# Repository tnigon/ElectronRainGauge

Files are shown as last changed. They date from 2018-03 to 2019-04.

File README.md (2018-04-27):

# Electron Weather Station


## Summary
This repository contains the files that I used to create a "cloud-connected" weather station via the [Particle Electron](https://store.particle.io/collections/electron). Please see [my how-to guide](http://tylernigon.me/projects/weather_station.html) describing the steps I took.

## Files
- The [circuit_board](https://github.com/tnigon/Electron_weather-station/tree/master/circuit_board) folder contains items for designing and manufacturing the printed circuit board (pcb).
- The [particle_code](https://github.com/tnigon/Electron_weather-station/tree/master/particle_code) folder contains the .ino files that contain the user-readable Particle code. These can be loaded or copied and pasted into Particle's [IDE](https://build.particle.io/build) to modify the code and/or compile to binary.
- [binary](https://github.com/tnigon/Electron_weather-station/tree/master/binary) contains a blank binary file that can be flashed to the Electron to stop publishing. This came in handy for me when troubleshooting my code and I didn't quite have it right.
- [webhook_templates](https://github.com/tnigon/Electron_weather-station/tree/master/webhook_templates) contains webhook templates for publishing your data to ThingSpeak or Weather Underground. Note that device ID and webhook name should be modified to be used with your device.

## Author
- [Tyler Nigon](https://tylernigon.me)

## License
This project is licensed under the GNU General Public License - see the [LICENSE.md](https://github.com/tnigon/Electron_weather-station/blob/master/LICENSE) for details

## Change log
- v2.0:
- v2.1:
- v2.2:

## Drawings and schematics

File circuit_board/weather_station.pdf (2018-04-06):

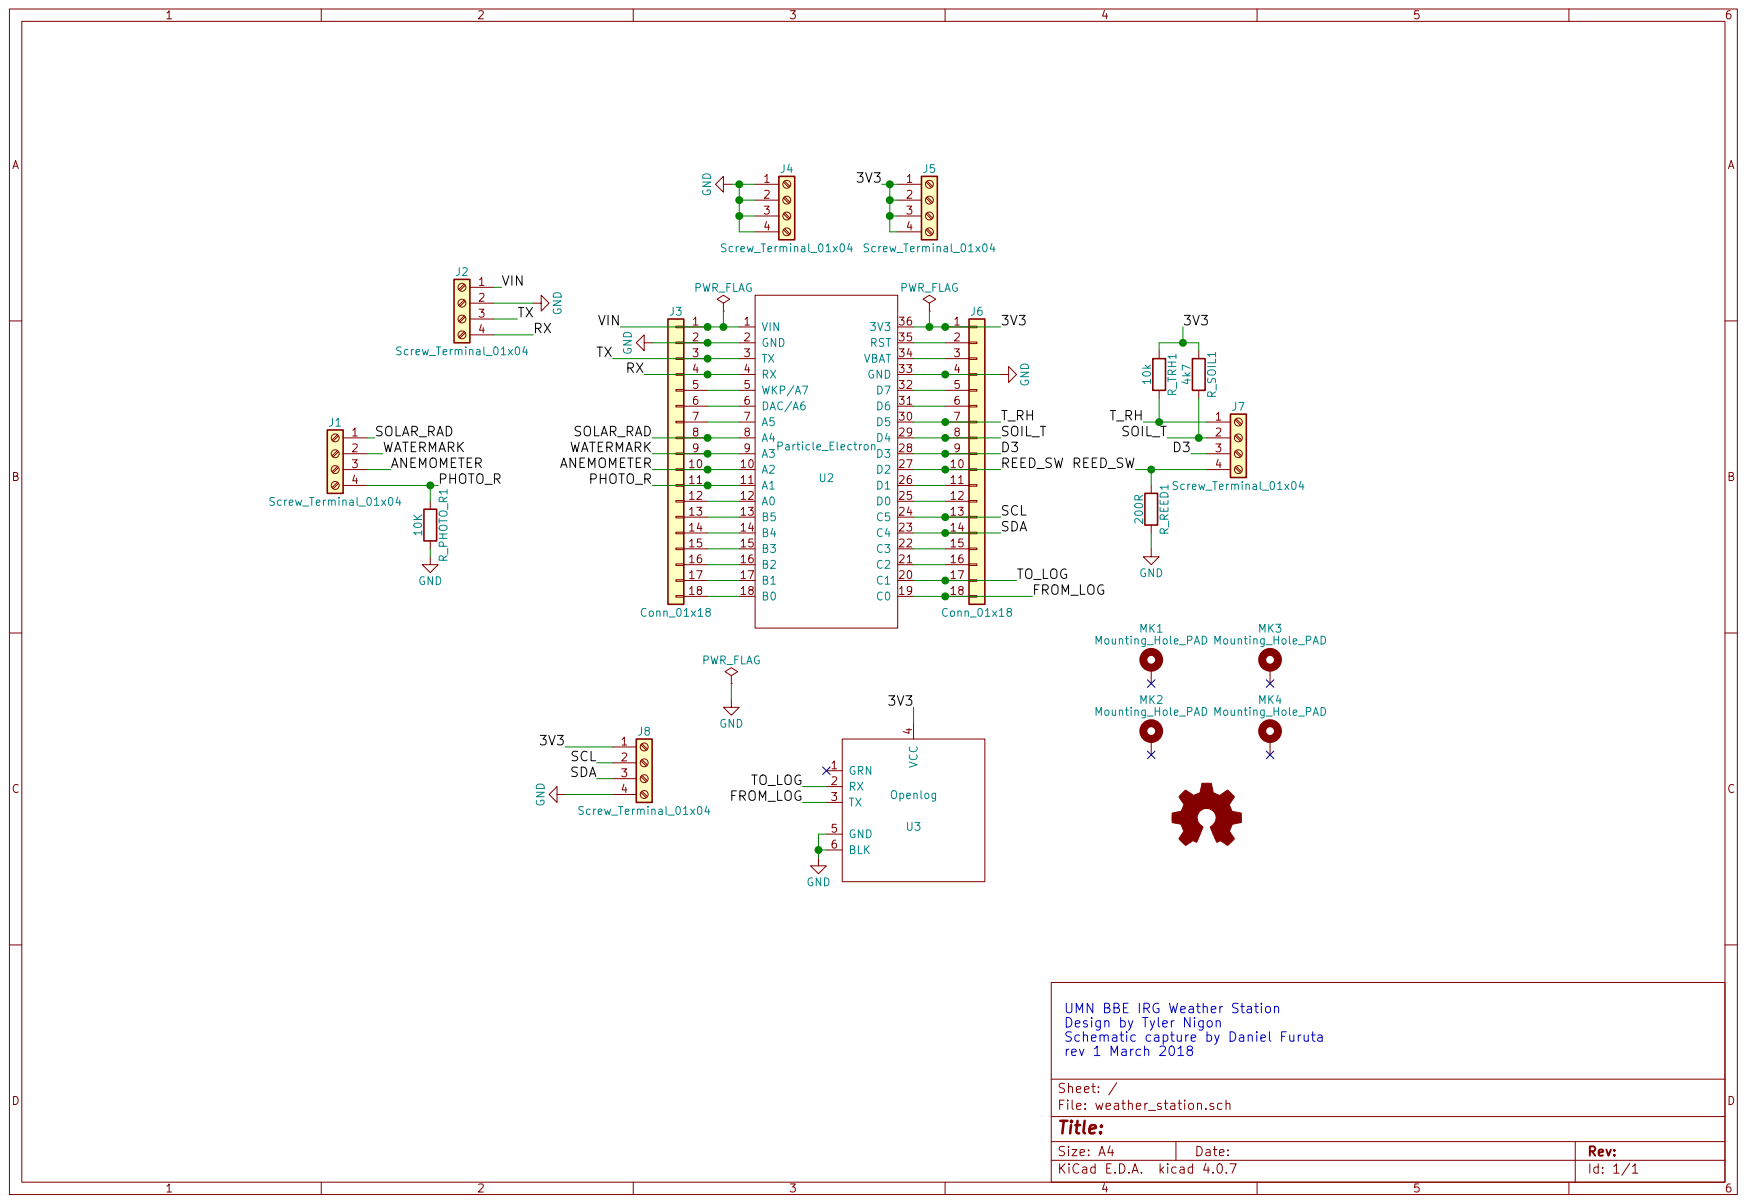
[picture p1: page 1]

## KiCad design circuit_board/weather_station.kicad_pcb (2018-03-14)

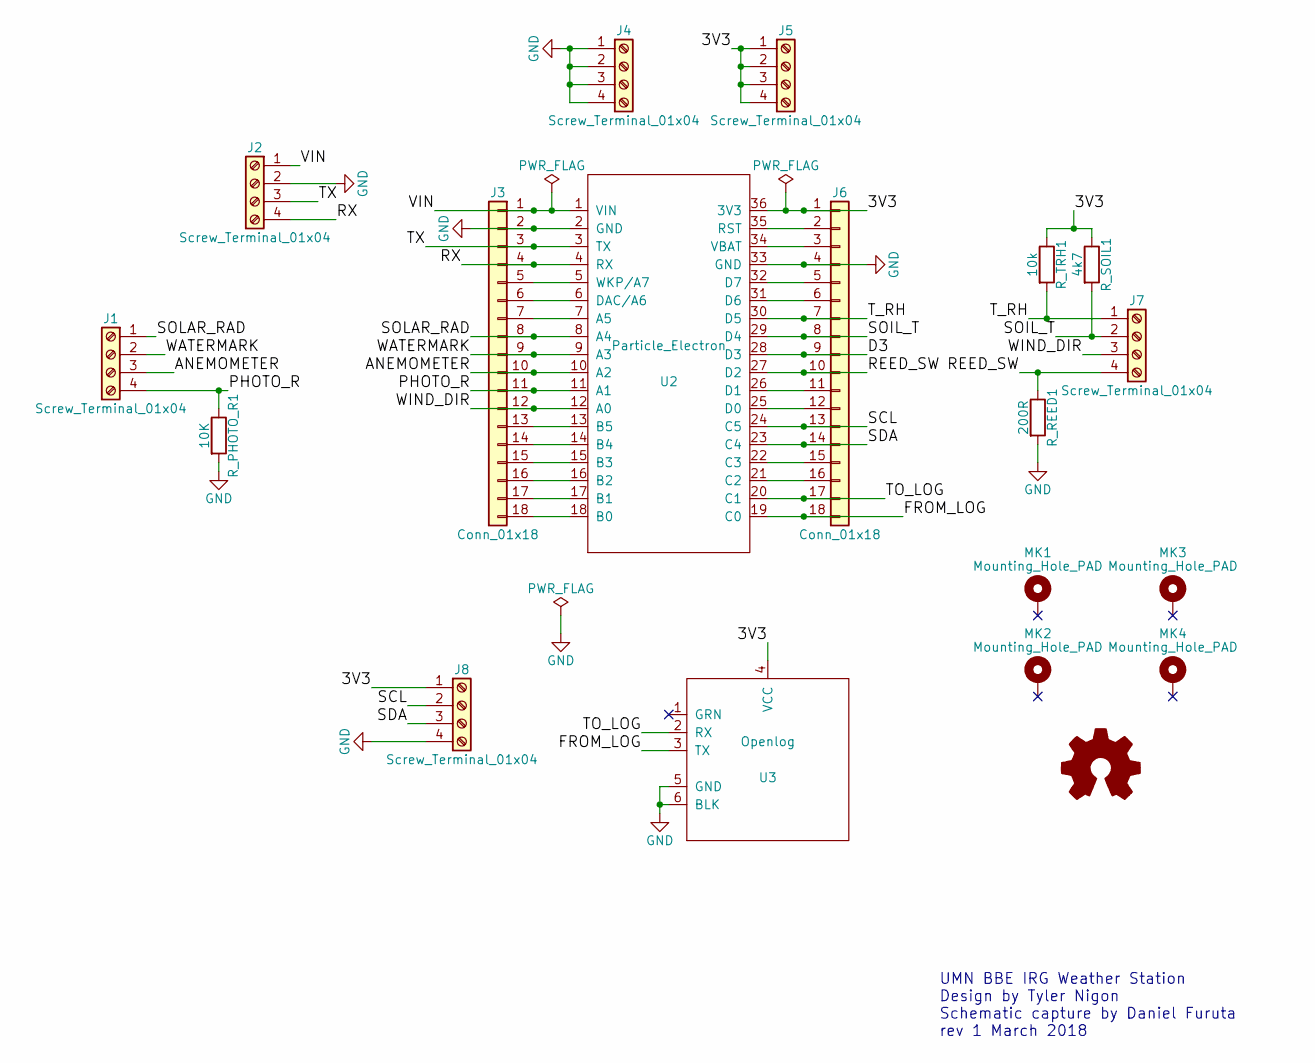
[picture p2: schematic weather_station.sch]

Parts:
J1, J2, J4, J5, J7, J8: Screw_Terminal_01x04; TerminalBlock_04x3.5mm_Straight
J3, J6: Conn_01x18; Pin_Header_Straight_1x18_Pitch2.54mm
MK1, MK2, MK3, MK4: Mounting_Hole_PAD; MountingHole_3mm_Pad
R_PHOTO_R1: 10K; R_TH_0.25W_400mil
R_REED1: 200R; R_TH_0.25W_400mil
R_SOIL1: 4k7; R_TH_0.25W_400mil
R_TRH1: 10k; R_TH_0.25W_400mil
U2: Particle_Electron
U3: Openlog

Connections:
/3V3: J5.1, J5.2, J5.3, J5.4, J6.1, J8.1, R_SOIL1.1, R_TRH1.1, U2.36 (3V3), U3.4 (VCC)
/ANEMOMETER: J1.3, J3.10, U2.10 (A2)
/D3: J6.9, U2.28 (D3)
/FROM_LOG: J6.18, U2.19 (C0), U3.3 (TX)
/PHOTO_R: J1.4, J3.11, R_PHOTO_R1.1, U2.11 (A1)
/REED_SW: J6.10, J7.4, R_REED1.1, U2.27 (D2)
/RX: J2.4, J3.4, U2.4 (RX)
/SCL: J6.13, J8.2, U2.24 (C5)
/SDA: J6.14, J8.3, U2.23 (C4)
/SOIL_T: J6.8, J7.2, R_SOIL1.2, U2.29 (D4)
/SOLAR_RAD: J1.1, J3.8, U2.8 (A4)
/TO_LOG: J6.17, U2.20 (C1), U3.2 (RX)
/TX: J2.3, J3.3, U2.3 (TX)
/T_RH: J6.7, J7.1, R_TRH1.2, U2.30 (D5)
/VIN: J2.1, J3.1, U2.1 (VIN)
/WATERMARK: J1.2, J3.9, U2.9 (A3)
/WIND_DIR: J3.12, J7.3, U2.12 (A0)
GND: J2.2, J3.2, J4.1, J4.2, J4.3, J4.4, J6.4, J8.4, R_PHOTO_R1.2, R_REED1.2, U2.2 (GND), U2.33 (GND), U3.5 (GND), U3.6 (BLK)
unnamed: J3.5, U2.5 (WKP/A7)
unnamed: J3.6, U2.6 (DAC/A6)
unnamed: J3.7, U2.7 (A5)
unnamed: J3.13, U2.13 (B5)
unnamed: J3.14, U2.14 (B4)
unnamed: J3.15, U2.15 (B3)
unnamed: J3.16, U2.16 (B2)
unnamed: J3.17, U2.17 (B1)
unnamed: J3.18, U2.18 (B0)
unnamed: J6.2, U2.35 (RST)
unnamed: J6.3, U2.34 (VBAT)
unnamed: J6.5, U2.32 (D7)
unnamed: J6.6, U2.31 (D6)
unnamed: J6.11, U2.26 (D1)
unnamed: J6.12, U2.25 (D0)
unnamed: J6.15, U2.22 (C3)
unnamed: J6.16, U2.21 (C2)

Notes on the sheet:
UMN BBE IRG Weather Station Design by Tyler Nigon Schematic capture by Daniel Furuta rev 1 March 2018

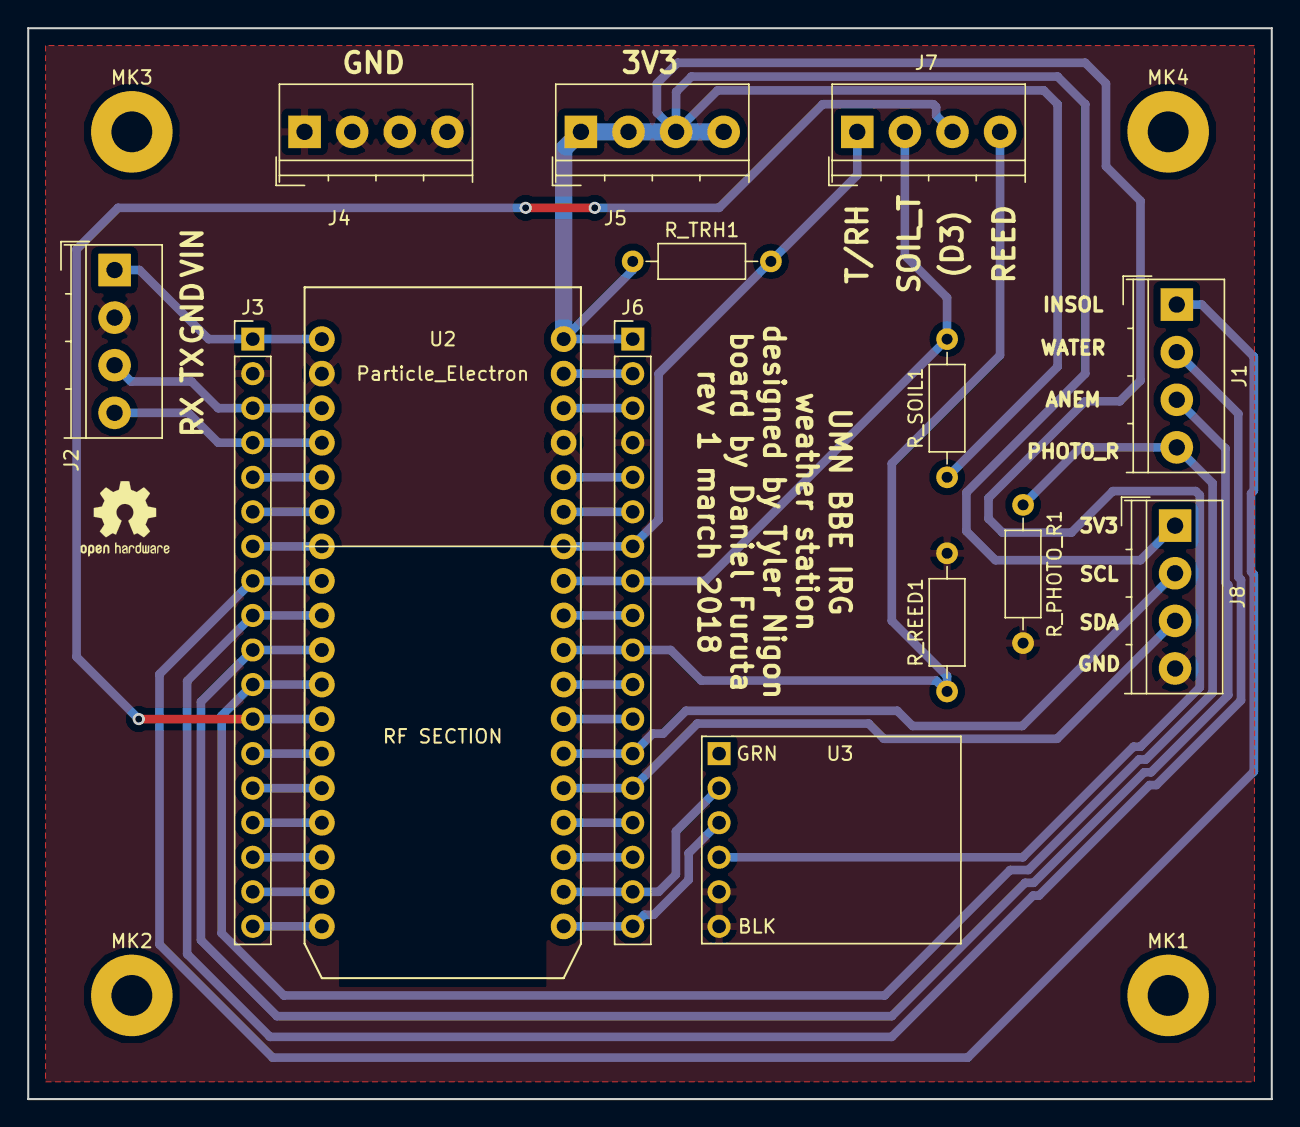
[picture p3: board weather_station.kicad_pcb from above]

Board: 2 copper layers, 91.4 x 78.7 mm, 18 parts (0 on the bottom side), 35 nets.

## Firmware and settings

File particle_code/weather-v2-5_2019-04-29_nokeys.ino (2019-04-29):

// This #include statement was automatically added by the Particle IDE.

#include <DHT.h> // Temp/humidity sensor
#include <Wire.h> // Lux sensor
#include <Adafruit_Sensor.h> // Lux sensor
#include <Adafruit_TSL2591.h> // Lux sensor
#include <DS18B20.h> // Waterproof temperature sensor
#include "Serial5/Serial5.h"

// Updated: 10 April 2019
// Author: Tyler J. Nigon

// For:
// Device name: <Particle device name>
// Device ID: <Particle device ID>
// Device firmware: <Electron device firmware>
// Code version: 2.5.0
// Owner: <Particle device owner>

// ============================================================
// Global user parameters
// ============================================================
// ***** Code version ******
String code_ver = "2.5.0";  // required for Weather Cloud

// ****** Time ******
boolean daylight_savings = true; // DST begins in spring and ends in fall
int gmt_timeZone = -6; // Change to appropriate time zone for your device
unsigned int sensorCapturePeriod = (30); // units are seconds
unsigned int publishPeriod = (60*10);  // units are seconds

// ****** Sensors ******
boolean sense_dht = true; // temp/humidity sensor
boolean sense_photo = false; // photoresistor light sensor
boolean sense_tsl = false; // tsl lux sensor
boolean sense_rain = true; // tipping bucket rain gauge
boolean sense_wind = true; // anemometer sensor
boolean sense_dir = false; // wind direction sensor
boolean sense_moist = false; // soil moisture sensor
boolean sense_soiltemp = true; // soil temperature sensor
boolean sense_solrad = false; // LI-200R pyranometer

// ****** Testing ******
boolean testing = false; // Uses benchTime instead of initialTime

// ****** Publishing ******
// ** If publishing via webhook, be sure channel, key/pw, name and number of variables are correct **
boolean units_imperial = false; // Temp, wind, and rain reported in imperial units (F, mph, & inches)

boolean publish_particle = false;
boolean publish_thingspeak = false;  // Go to #1
boolean publish_wunderground = false;  // Go to #2
boolean publish_weathercloud = true;  // Got to #3
boolean publish_serial = false;  // Go to #4
boolean publish_sd = false;

// [1: Thinkgspeak]
unsigned long thingspeakChannelNumber = 012345;
String api_key = ""; // ThingSpeak Write API Key.
String webhook_ts_str = ""; // Name of webhook - must match from "Integrations" page
// [2: Weather Underground]
String wu_stationID = ""; // From WUnderground account
String wu_password = "";
String webhook_wu_str = "";
// String webhook_wu_str_rain = "webhook_wunderground_rain";
// String webhook_wu_str_norain = "webhook_wunderground_norain";
// [3: Weather Cloud]
String weathercloud_id = "";  // From Weather Cloud account
String weathercloud_key = "";
String weathercloud_type = "d407ac9be248";  // Device code from WeatherCloud
String webhook_wc_str = "";
// [4: Serial/SD]
SYSTEM_MODE(SEMI_AUTOMATIC); // Allows device to output to serial without being connected to the cloud

// ****** Sensors & pins ******
#define DHTPIN 5
#define DHTTYPE DHT22  // DHT11 (blue) or DHT22 (white)
DHT dht(DHTPIN, DHTTYPE);
int light_sensor_pin = A1;
// const int sleep_pin = D1;
const int RainPin = D2;
const int anemometerPin = A2;
const int wind_dir_pin = A0;
DS18B20 ds18b20(D4, true); // Waterproof temperature sensor
const int led = D7;
const int soil_moist_pin = A3;
int ledState = LOW; // ledState used to set the LED
// Adafruit_ADS1115 ads1115;
Adafruit_TSL2591 tsl = Adafruit_TSL2591(2591); // lux - 2591 identifies the sensor (multiple possible)
int solrad_sensor_pin = A4;
// ParticleSoftSerial SoftSer(C0, C1);

// ****** Other global variables ******
boolean cloud_connect;
float offsetDST = Time.getDSTOffset(); // Get current DST offset; default is +1.0
unsigned int sensorCount = 1; // this provides 32 bits of dynamic range
unsigned int publishCount = 1;
time_t benchTime;
time_t initialTime;
time_t endOfDay;
time_t scheduledSensor;
time_t scheduledPublish;
time_t time_wake;
time_t wake_secs;
String end_day;
boolean first_loop = true;
String header;

float dilToday = 0; // Daily Integrated Light (mol / m2 / day); resets at midnight
float lux2par = (1/54);
float dil_conversion = lux2par * (1/1000000) * (sensorCapturePeriod); // lux to par and micromoles to moles and seconds to "sensorCapturePeriod" (e.g., 5 seconds)
float solrad_offset = 2; // determine offset by disconnecting sensor from voltage amplifier and monitor voltage output
float solrad_gain = 0.05;  // units of V per microamp
float solrad_const = 62.28; // units of microamps per 1000 watts per m2 (this calibration constant comes from the Li-Cor certificate of calibration)
float solrad_conversion = 1/(solrad_gain * solrad_const); // in units of kW m-2 V-1 --> use this to directly convert voltage output to W m-2
// ============================================================

// Sensors
float tempC;
float humidityRH;
float dewPointC;
double Td_a = 17.271;  // Constants for dew point calculation
double Td_b = 237.7;  // See http://en.wikipedia.org/wiki/Dew_point
float heatIndexC;
float temp_f;
float dewPoint_f;
float heatIndex_f;
float light;
float lux;
float lux_tot;
float lux_n;
float par;
float dil_increment;
float soil_temp_C;
float soil_temp_F;
float wind_mps;
float wind_gust;
float wind_mph;
float windGust_mph;
float wind_dir;
float rainRateMultiplier;  // this variable extrapolates so hourly rate can be reported based on the chosen publishPeriod
float rain_mm;
float hourly_rain_mm;
float rainToday_mm;
float rain_in;
float hourly_rain_in;
float rainToday_in;
float soilMoisture;
float sol_rad_wm2;
float sol_rad_MJ;
float solrad_today_MJ;
// pin_t wakeUpPins[2] = {sleep_pin, RainPin};  // Initialize sleep settings
// InterruptMode edgeTriggerModes[2] = {RISING, RISING};  // wakes Electron if either wake-up pin is RISING

String pub_dewPointC;
String pub_hum;
String pub_heatIndexC;
String pub_hourly_rain_mm;
String pub_rainToday_mm;
String pub_soilMoisture;
String pub_soil_temp_C;
String pub_sol_rad_wm2;
String pub_tempC;
String pub_wind_gust_mps;
String pub_wind_mps;

int wc_dewPointC;
int wc_hum;
int wc_heatIndexC;
int wc_hourly_rain_mm;
int wc_rainToday_mm;
int wc_soilMoisture;
int wc_soil_temp_C;
int wc_sol_rad_wm2;
int wc_tempC;
int wc_wind_gust_mps;
int wc_wind_mps;

// ============================================================
// Functions
// ============================================================
void setup();
void loop();
String hhmmss();
String yyyymmdd();
void test_sensors();
// void put_to_sleep();
void sd_serial_setup();
void blinkLight();
void captureTempHumidity();
float getAndResetTempC();
float getAndResetHumidityRH();
float getAndResetDewPointC();
float getAndResetHeatIndex();
void captureLight();
float getAndResetLight();
void captureLux();
float getAndResetLux();
float getAndResetLux1();
float getAndResetParDIL();
void captureSoilMoisture();
float getAndResetSoilMoisture();
void capture_soil_temp();
float getAndResetSoilTempC();
void initializeRainGauge();
void handleRainEvent();
float getAndResetRain();
void captureWind();
float getAndResetAnemometer();
void initializeWindVane();
void captureWindVane();
float getAndResetWindVaneDegrees();
float lookupRadiansFromRaw();
void capture_sol_rad_MJ();
float getAndResetSolrad();
void publishToSerial();
void publishToParticle();
void create_pub_json();
void publishToThingSpeak();
void publishToWeatherCloud();
void publishToWUndergroundRain();
void publishToWUndergroundAll();
void publishToWUndergroundNoRain();
void createThingSpeakjson();
void create_WC_json();
void createWUjsonAll();
void createWUndergroundjsonRain();
void createWUndergroundjsonNoRain();
double mapDouble();
// ============================================================

void setup() {
    // if (publish_serial == true) {
    Serial.begin(9600); // Required if publishing to Serial
    // }
    if ((publish_particle == true) || (publish_thingspeak == true) || (publish_weathercloud == true) || (publish_wunderground == true)) {
        cloud_connect = true;
        Particle.connect();
        delay(3000); // delay to let Particle get connected so time is correct
        while (Particle.connected() == false) {
            delay(1000); // delay to let Particle get connected so time is correct
        }
        Particle.publish("cloud_connect = true");
    }
    else {
        cloud_connect = false;
    }
    // ============================================================
    // Time
    // ============================================================
    pinMode(led, OUTPUT);
    benchTime = Time.now();
    while (Time.year(benchTime) < 2018) {
    // while (Time.year(benchTime < 2018)) {
        Particle.publish("benchTime is not correct: ", yyyymmdd(benchTime));
        Particle.publish("benchTime is not correct: ", hhmmss(benchTime));
        benchTime = Time.now();
        delay(5000);
    }
    if (cloud_connect == true) {
        Particle.publish("Initial system time is: ", hhmmss(benchTime));
      }
    // while (benchTime < 3600) {
    //     benchTime = Time.now(); // So all times are consistently calculated (it could presumably take several seconds to get through all code in which case times will be misaligned)
    // }
    if (Time.minute(benchTime) >= 30) {
        initialTime = benchTime + ((59 - Time.minute(benchTime))*60) + (60 - Time.second(benchTime)); // ensures initial time will be at top of the hour
        if (Time.hour(initialTime) < abs(gmt_timeZone)) {
            endOfDay = initialTime - ((Time.hour(initialTime))*60*60) - (gmt_timeZone*60*60);
        }
        else {
            endOfDay = initialTime + ((24 - Time.hour(initialTime))*60*60) - (gmt_timeZone*60*60);
        }
    }
    if (Time.minute(benchTime) < 30) {
        initialTime = benchTime + ((29 - Time.minute(benchTime))*60) + (60 - Time.second(benchTime)); // ensures initial time will be at bottom of the hour
        if (Time.hour(initialTime) < abs(gmt_timeZone)) {
            endOfDay = initialTime - ((Time.hour(initialTime))*60*60) - (gmt_timeZone*60*60) - (30*60); // benchTime.day is already tomorrow
        }
        else {
            endOfDay = initialTime + ((24 - Time.hour(initialTime))*60*60) - (gmt_timeZone*60*60) - (30*60); // benchTime.day is still today
        }
    }
    if (daylight_savings == true) {
        endOfDay -= int(offsetDST*60*60);  // Adding int makes the math correct; otherwise there's an extra 48 seconds..
    }

    // ============================================================
    // First publish will be at first top or bottom of the hour
    // (unless in testing mode)
    // ============================================================
    scheduledSensor = benchTime + sensorCapturePeriod; // schedule initial sensor reading immediately
    time_wake = scheduledPublish;  //  initialize so can go to sleep after first publish
    if (testing == true) {
        scheduledPublish = benchTime + publishPeriod;
    }
    else {
        scheduledPublish = initialTime; // schedule first publish at first top (or bottom) of the hour
    }
    end_day = yyyymmdd(endOfDay) + "T" + hhmmss(endOfDay);

    if (cloud_connect == true) {
        Particle.publish("Initial system time is: ", hhmmss(benchTime));
        delay(1000);
        Particle.publish("Data will begin being collected at: ", hhmmss(scheduledSensor));
        delay(1000);
        Particle.publish("Data will first be published at: ", hhmmss(scheduledPublish));
        delay(4000);
        Particle.publish("GMT Time zone is: ", String(gmt_timeZone));
        delay(1000);
        if (daylight_savings == true) {
            Particle.publish("Daylight savings time: ", String("True"));
        }
        else {
            Particle.publish("Daylight savings time: ", String("False"));
        }
        delay(1000);
        Particle.publish("Local end of day (UTC): ", end_day); // this is a check - should be +05:00:00 for CST during DST
    }
    else {
      Serial.print(("Initial system time is: ")), String(hhmmss(benchTime));
      delay(1000);
      Serial.print("Data will begin being collected at: "), String(hhmmss(scheduledSensor));
      delay(1000);
      Serial.print("Data will first be published at: "), String(hhmmss(scheduledPublish));
      delay(4000);
      Serial.print("GMT Time zone is: "), String(gmt_timeZone);
      delay(1000);
      if (daylight_savings == true) {
          Serial.print("Daylight savings time: "), String("True");
      }
      else {
          Serial.print("Daylight savings time: "), String("False");
      }
    }

    if (publish_sd == true) {
        Serial5.begin(9600);
        delay(50);
        // Note: SoftSer gave currupt characters on first line write; using Serial5 instead
        // SoftSer.begin(9600, SERIAL_8N1);
    }

    // ============================================================
    // Initialize Digital Sensors
    // ============================================================
    if (sense_dht == true) {
        dht.begin(); // Start DHT sensor
    }
    if (sense_rain == true) {
        initializeRainGauge();
        rainRateMultiplier = 60 / (publishPeriod/60);
    }
    // if (sense_moist == true) {
    //     ads1115.begin();  // Initialize ads1115
    //     ads1115.setGain(GAIN_ONE); // 16x gain +/- 0.256V 1 bit = 0.125mV
    // }
    if (sense_tsl == true) {
        Wire1.begin();
        tsl.begin();
        tsl.setGain(TSL2591_GAIN_LOW);    // LOW, MED, or HIGH for 1x, 25x, or 428x, respectively
        tsl.setTiming(TSL2591_INTEGRATIONTIME_100MS);  // can range from 100MS to 600MS (in increments of 100MS)
    }
    sd_serial_setup();
    test_sensors();
    delay(10);
    // put_to_sleep();
}

void loop() {
    blinkLight(); // To initialize currentMillis variable

    // ================================================================
    // Sensors
    // Electron will wake up 3 seconds before scheduledSensor, then
    // run for the entire loop() function before going back to sleep
    // ================================================================
    if(Time.now() >= scheduledSensor) {
      if (sense_dht == true) {
        captureTempHumidity();
      }
      if (sense_photo == true) {
        captureLight();
      }
      if (sense_tsl == true) {
        captureLux();
      }
      if (sense_moist == true) {
        captureSoilMoisture();
      }
      if (sense_soiltemp == true) {
        capture_soil_temp();
      }
      if (sense_wind == true) {
        captureWind();
      }
      if (sense_solrad == true) {
        capture_sol_rad_MJ();
      }
      sensorCount++;
      scheduledSensor = benchTime + (sensorCount*sensorCapturePeriod);
    }
    // ================================================================
    // Publish
    // Electron will wake up 6 seconds before scheduledPublish, then
    // run for the entire loop() function before going back to sleep
    // ================================================================
    if (Time.now() >= scheduledPublish) {
        if ((cloud_connect == true) && (Particle.connected() == false)) {
            Particle.connect();
        }

        // float tempC;
        // float humidityRH;
        // float dewPointC;
        // float temp_f;
        // float dewPoint_f;
        if (sense_dht == true) {
            tempC = getAndResetTempC(); // Get the data to be published
            humidityRH = getAndResetHumidityRH();
            dewPointC = getAndResetDewPointC();
            heatIndexC = getAndResetHeatIndex();
            if (units_imperial == true) {
                temp_f = (32 + (tempC * 1.8));
                dewPoint_f = (32 + (dewPointC * 1.8));
                heatIndex_f = (32 + (heatIndexC * 1.8));
            }
        }

        // float light;
        if (sense_photo == true) {
            light = getAndResetLight();
        }

        // float lux;
        // float lux_tot;
        // float lux_n;
        // float par;
        // float dil_increment;
        if (sense_tsl == true) {
            lux = getAndResetLux();
            getAndResetParDIL(&par, &dil_increment);
            dilToday += dil_increment;
        }

        // float soilMoisture;
        if (sense_moist == true) {
            soilMoisture = getAndResetSoilMoisture();
        }

        // float soil_temp_C;
        // float soil_temp_F;
        if (sense_soiltemp == true) {
            soil_temp_C = getAndResetSoilTempC();
            if (units_imperial == true) {
                soil_temp_F = (32 + (soil_temp_C * 1.8));
            }
        }

        // float wind_mps;
        // float wind_gust;
        // float wind_mph;
        // float windGust_mph;
        if (sense_wind == true) {
            getAndResetAnemometer(&wind_mps, &wind_gust);
            if (units_imperial == true) {
                wind_mph = (wind_mps * 2.23694);
                windGust_mph = (wind_gust * 2.23694);
            }
        }

        // float rain_mm;
        // // float rainToday_mm;
        // float rain_in;
        // float rainToday_in;
        rain_mm = getAndResetRain();
        hourly_rain_mm = rain_mm*rainRateMultiplier;
        rainToday_mm += rain_mm;
        if (units_imperial == true) {
            rain_in = (rain_mm * 0.0393701);
            hourly_rain_in = rain_in*rainRateMultiplier;
            rainToday_in = (rainToday_mm * 0.0393701);
        }

        // float wind_dir;
        if (sense_dir == true) {
            wind_dir = getAndResetWindVaneDegrees();
        }

        if (sense_solrad == true) {
            // multiply by capture period to integrate over time
            // convert kW m-2 (kJ s-1) to megajoules by dividing by 1000
            sol_rad_wm2 = (getAndResetSolrad() * sensorCapturePeriod);
            sol_rad_MJ = sol_rad_wm2 / 1000;
            solrad_today_MJ += sol_rad_MJ;
        }

        // FuelGauge fuel;
        // float voltage = fuel.getVCell(); // Battery voltage
        // float bat_percent = fuel.getSoC(); // State of Charge from 0-100%
        if (publish_serial == true) {
          Particle.publish("Data will first be published at: ", hhmmss(scheduledPublish));
            if (units_imperial == false) {
                publishToSerial_metric(tempC,humidityRH,dewPointC,heatIndexC,light,lux,dilToday,rainToday_mm,wind_mps,wind_gust,soil_temp_C,solrad_today_MJ,soilMoisture);
            }
            else if (units_imperial == true) {
                publishToSerial_imperial(temp_f,humidityRH,dewPoint_f,heatIndex_f,light,lux,dilToday,rainToday_in,wind_mph,windGust_mph,soil_temp_F,solrad_today_MJ,soilMoisture);
                // publishToSerial_imperial(temp_f,humidityRH,rainToday_in,wind_mph,windGust_mph,soil_temp_F,solrad_today_MJ);
            }

        }
        if (publish_particle == true) {
            if (units_imperial == false) {
                publishToParticle(tempC,dewPointC,humidityRH,heatIndexC,soil_temp_C,wind_mps,wind_gust,hourly_rain_mm,rainToday_mm,soilMoisture,sol_rad_wm2);
            }
            else if (units_imperial == true) {
                publishToParticle(tempC,dewPointC,humidityRH,heatIndexC,soil_temp_C,wind_mps,wind_gust,hourly_rain_mm,rainToday_mm,soilMoisture,sol_rad_wm2);
                // publishToParticle(temp_f,humidityRH,light,rainToday_in,wind_mph,windGust_mph,soil_temp_F);
            }
        }
        if (publish_thingspeak == true) {
            if (units_imperial == false) {
                publishToThingSpeak(tempC,humidityRH,solrad_today_MJ,rainToday_mm,wind_mps,wind_gust,soil_temp_C,soilMoisture);
            }
            else if (units_imperial == true) {
                publishToThingSpeak(temp_f,humidityRH,solrad_today_MJ,rainToday_in,wind_mph,windGust_mph,soil_temp_F,soilMoisture);
            }
        }
        if (publish_wunderground == true) {
            if (units_imperial == false) {
                publishToWUndergroundAll(tempC,humidityRH,dewPointC,heatIndexC,wind_mps,wind_gust,soil_temp_C,hourly_rain_mm,rainToday_mm);
            }
            else if (units_imperial == true) {
                publishToWUndergroundAll(temp_f,humidityRH,dewPoint_f,heatIndex_f,wind_mph,windGust_mph,soil_temp_F,hourly_rain_in,rainToday_in);
            }
            // if (rainToday_mm > 0.0) { // If it rained today, publish rainfall data for the rest of the day
            //     if (units_imperial == false) {
            //         publishToWUndergroundRain(tempC,humidityRH,wind_mps,wind_gust,soil_temp_C,rain_mm,rainToday_mm);
            //     }
            //     else if (units_imperial == true) {
            //         publishToWUndergroundRain(temp_f,humidityRH,wind_mph,windGust_mph,soil_temp_F,rain_in,rainToday_in);
            //     }
            // }
            // else { // Do not publish rain data unless it has rained today
            //     if (units_imperial == false) {
            //         publishToWUndergroundNoRain(tempC,humidityRH,wind_mps,wind_gust,soil_temp_C);
            //     }
            //     else if (units_imperial == true) {
            //         publishToWUndergroundNoRain(temp_f,humidityRH,wind_mph,windGust_mph,soil_temp_F);
            //     }
            // }
        }
        if (publish_weathercloud == true) {
            // Weather Cloud requires metric units (they handle conversions on their website)
            publishToWeatherCloud(tempC,dewPointC,humidityRH,heatIndexC,soil_temp_C,wind_mps,wind_gust,hourly_rain_mm,rainToday_mm,soilMoisture,sol_rad_wm2);
        }
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

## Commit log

2017-04-25 fritzing wiring diagram added
    [ElectronWeatherProtoboard.fzz, Protoboard.fzz, feed.csv]
2017-05-02 updating the anemometer for voltage output
    [ElectronWeatherProtoboard.fzz, feed.csv]
2017-07-15 cleaning up files
    [ElectronWeather_Protoboard.fzz, Protoboard.fzz]
2018-03-14 adding PCB breakout board
    [weather_station.kicad_pcb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]
2018-04-26 adding v2.2 and organizing into folders
    [ElectronWeather_Protoboard.fzz, ElectronWeather_Protoboard2.fzz, ElectronWeather_Protoboard3.fzz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]
2018-04-26 remove .fzz
    [ElectronWeather_Protoboard.fzz]
2018-04-27 correcting solar radiation equations
    [weather-v2-2_2018-04-27_nokeys.ino]
2018-12-12 correcting watermark equation and removing unused libraries
    [weather-v2-4_2018-12-12_nokeys.ino]
